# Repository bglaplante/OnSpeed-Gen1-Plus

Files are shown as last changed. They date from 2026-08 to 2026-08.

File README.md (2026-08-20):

# OnSpeed-Gen1-Plus
Takes the original OnSpeed Gen1, ports to Arduino Mega

The original work at https://github.com/flyonspeed-org/OnSpeed-Gen1 used a $50 Due board.
I have ported the project to the Mega, which is sufficient as the Gaussian average was turned off.
This required changing timer libraries and a substantial rework of the code.

Currently as of August 2026, the project has been tested successfully with the Dynon D10A,
which means it works with that and the whole D100 series.

In addition it supports Skyview, and has been bench tested with a data generator emulating
Skyview data.

Garmin G3X is planned.

The project includes an LED display which shows the current reported AOA percent.
This simplifies configuration - you do a test flight at various slow flight speeds and record the reported AOA % values.
Then you can (post-flight) determine the starting thresholds for each OnSpeed point.
Those thresholds can then be placed onto an SD card.  When the system starts, it reads the SD card for configuration values.

A circuit board has been designed to hold the Mega Pro Mini, RS232 converter, LED display, SD card reader, and Step Down power supply.

Licensed under the NC-MIT 1.1 License. See LICENSE file in the project root.

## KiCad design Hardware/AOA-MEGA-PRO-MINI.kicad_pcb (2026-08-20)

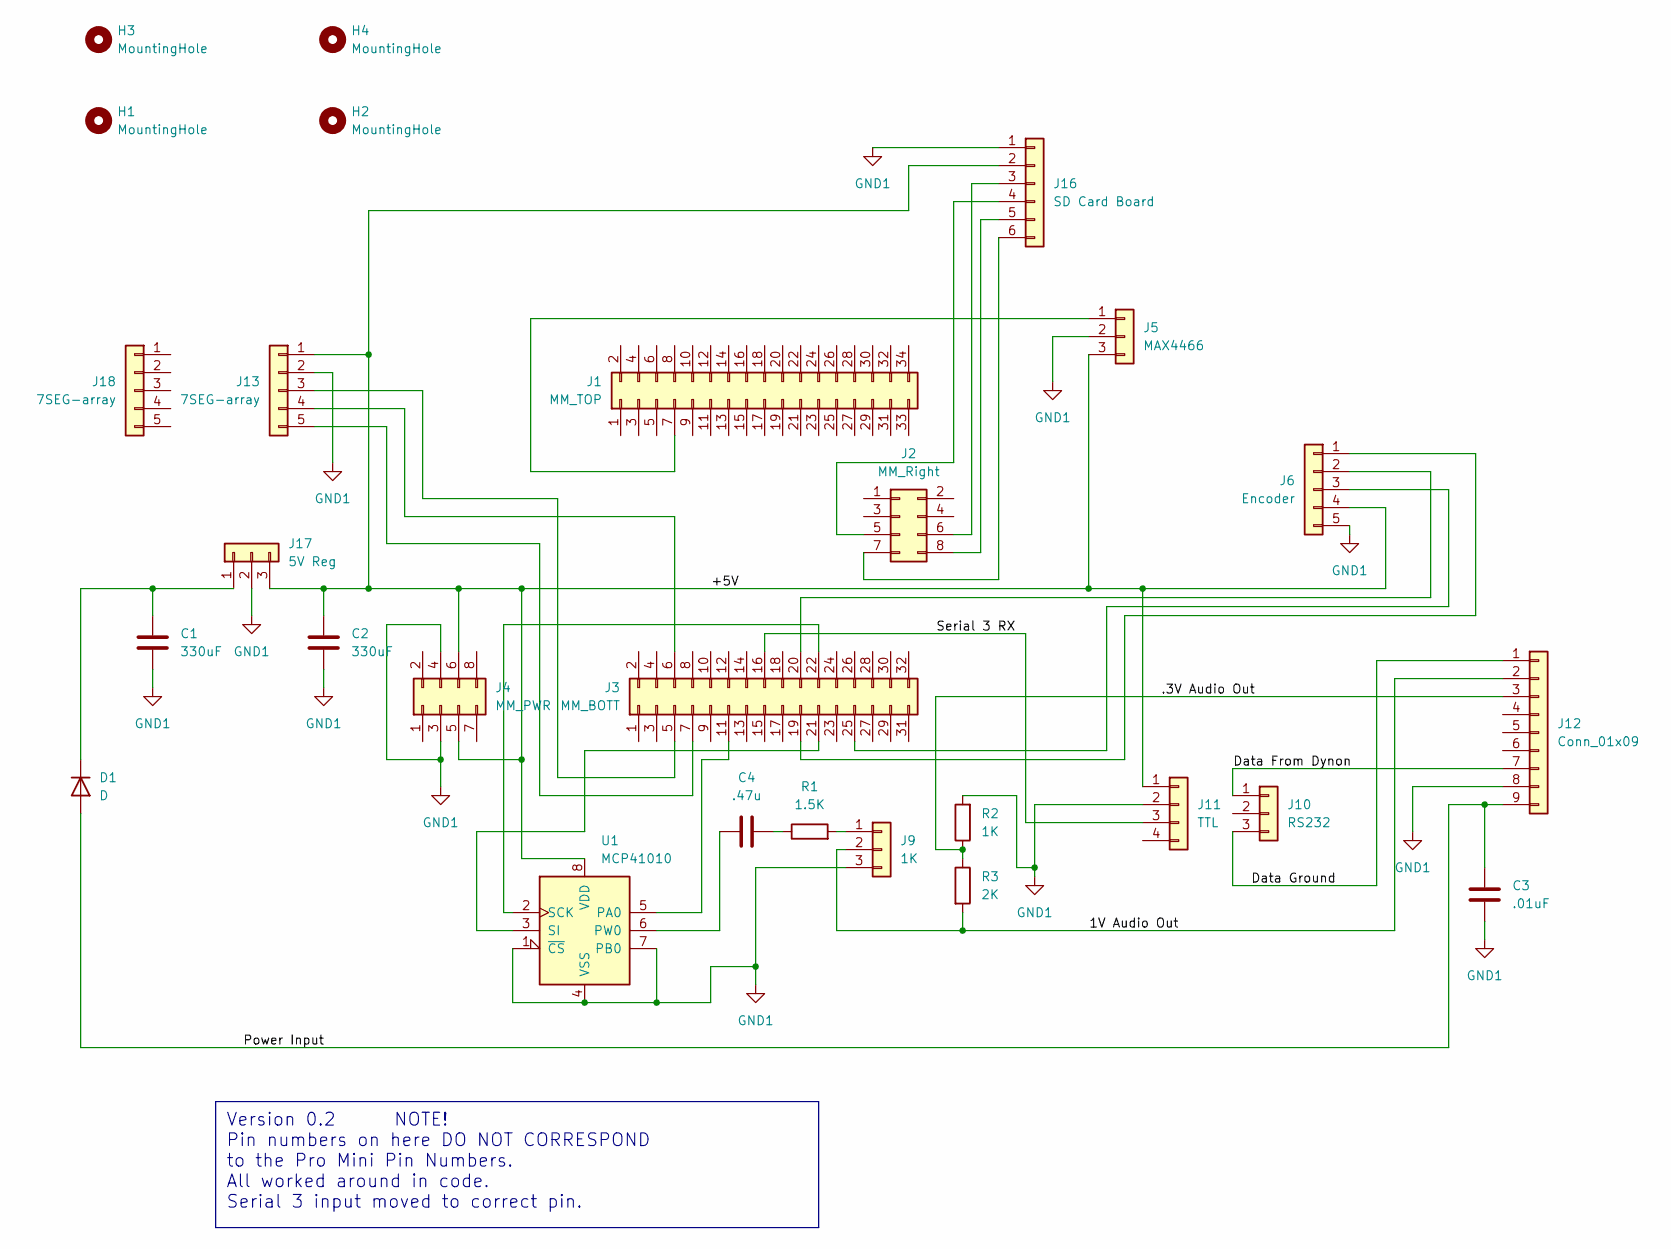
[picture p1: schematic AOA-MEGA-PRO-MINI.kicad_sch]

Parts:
C1, C2: 330uF; CP_Radial_D10.0mm_P5.00mm_P7.50mm
C3: .01uF; CP_Radial_D8.0mm_P5.00mm
C4: .47u; CP_Radial_D7.5mm_P2.50mm
D1: D; D_5W_P10.16mm_Horizontal
H1, H2, H3, H4: MountingHole; MountingHole_3.2mm_M3
J1: MM_TOP; PinSocket_2x17_P2.54mm_Vertical
J2: MM_Right; PinSocket_2x04_P2.54mm_Vertical
J3: MM_BOTT; PinSocket_2x16_P2.54mm_Vertical
J4: MM_PWR; PinSocket_2x04_P2.54mm_Vertical
J5: MAX4466; PinSocket_1x03_P2.54mm_Vertical
J6: Encoder; PinSocket_1x05_P2.54mm_Vertical
J9: 1K; PinSocket_1x03_P2.54mm_Vertical
J10: RS232; PinSocket_1x03_P2.54mm_Vertical
J11: TTL; PinSocket_1x04_P2.54mm_Vertical
J12: Conn_01x09; PinSocket_1x09_P2.54mm_Vertical
J13, J18: 7SEG-array; PinSocket_1x05_P2.54mm_Vertical
J16: SD Card Board; PinSocket_1x06_P2.54mm_Vertical
J17: 5V Reg; PinSocket_1x03_P2.54mm_Vertical
R1: 1.5K; R_1206_3216Metric
R2: 1K; R_1206_3216Metric
R3: 2K; R_1206_3216Metric
U1: MCP41010; DIP-8_W7.62mm

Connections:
/1V Audio Out: J9.2, J12.2, R3.2
/+5V: C2.1, J4.5, J4.6, J5.3, J6.4, J11.1, J13.1, J16.2, J17.3, U1.8 (VDD)
/.3V Audio Out: J12.3, R2.1, R3.1
/Data From Dynon: J10.1, J12.7
/Data Ground: J10.3, J12.1
/Power Input: C3.1, D1.2 (A), J12.9
/Serial 3 RX: J3.16, J11.3
GND1: C1.2, C2.2, C3.2, J4.3, J4.4, J5.2, J6.5, J9.3, J11.2, J12.8, J13.2, J16.1, J17.2, R2.2, U1.1 (~CS), U1.4 (VSS), U1.7 (PB0)
unnamed: C4.2, R1.1
unnamed: C1.1, D1.1 (K), J17.1
unnamed: J1.7, J5.1
unnamed: J3.11, U1.5 (PA0)
unnamed: J3.19, J6.1
unnamed: J3.20, J6.2
unnamed: J3.21, U1.3 (SI)
unnamed: J3.22, U1.2 (SCK)
unnamed: J3.25, J6.3
unnamed: J9.1, R1.2
unnamed: J3.5, J13.3
unnamed: J3.6, J13.4
unnamed: J3.7, J13.5
unnamed: J2.6, J16.3
unnamed: J2.5, J16.4
unnamed: J2.8, J16.5
unnamed: J2.7, J16.6
unnamed: C4.1, U1.6 (PW0)

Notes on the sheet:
Version 0.2 NOTE! Pin numbers on here DO NOT CORRESPOND to the Pro Mini Pin Numbers. All worked around in code. Serial 3 input moved to correct pin.

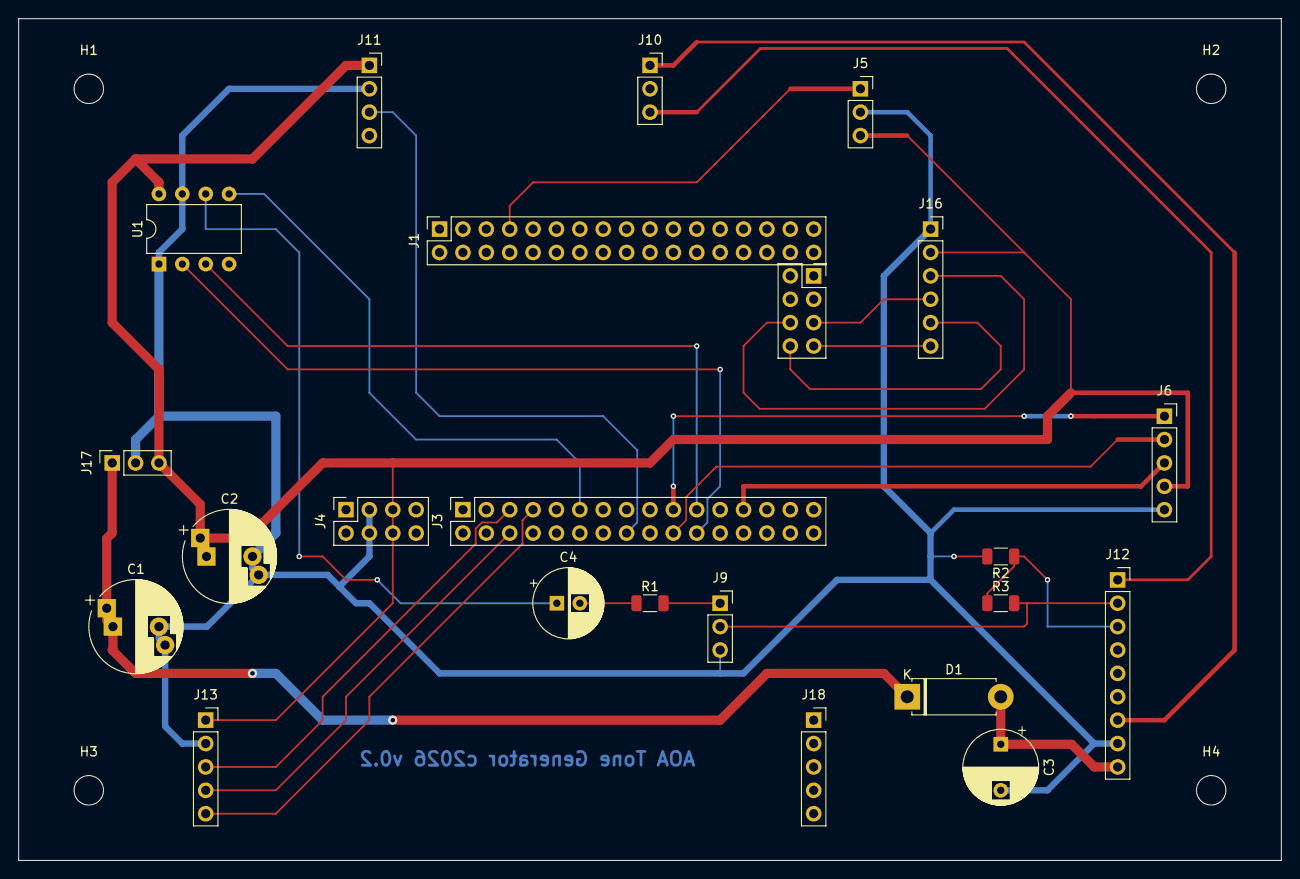
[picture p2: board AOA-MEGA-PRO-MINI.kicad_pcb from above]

Board: 2 copper layers, 137.2 x 91.4 mm, 27 parts (0 on the bottom side), 26 nets.

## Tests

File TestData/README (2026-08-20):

Arduino code to generate Dynon D10A message strings, and to rapidly output them.
By sending strings rapidly and within the range of pulse tone generation speeds we can stress test the system 
to confirm that we do not get data overruns which can lead to lock-up.

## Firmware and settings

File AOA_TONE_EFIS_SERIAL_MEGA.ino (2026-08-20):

////////////////////////////////////////////////////
////////////////////////////////////////////////////
// AOA EFIS Serial to audio tone 
// Supports: Dynon EFIS data using a Arduino Mega board
// Ver 1.7.4
#define VERSION "174"

// NOTE *********  The Arduino default serial buffer is smaller than the Skyview packet,
// it seems that there could easily be an overflow situation.
// however, testing on 8/18, shows can handle Skyview at 100 msgs per second @ SAMPLE_RATE 3
// Bryan LaPlante 8/17/2026 ---  code review Skyview and handle AOA = "XX" it can send 
// Bryan LaPlante 8/12/2026 ---  testing shows no more lockups.  Updated AOA thresholds for N980RV
// Bryan LaPlante 7/1/2026  ---  still get lockups probably buffer overflows... fix volatile vars...
// Bryan LaPlante 6/21/2026 --- pre-calc the pps vs AOA, to eliminate float point (slow) from main loop
// Bryan LaPlante 6/17/2026 --- increase min speed for tones to 15 (at 5 it is alive standing still!)
// Bryan LaPlante 6/14/2026  --- eliminate dual set points ... (Skyview / D100x)
// Bryan LaPlante 11/27/2025 --- read AOA set points from SD card (D10/100 only for now)
// Bryan LaPlante 11/23/2025 --- convert to Mega (for dual hardware serial ports)
// Bryan LaPlante 10/21/2025 --- conversion to Nano, TimerOne, 


//
// - Read data in from Serial3 on MEGA board. (Dynon is at 115200 baud)
// - Serial is used for debugging to computer IDE. (115200 baud)
// - Audio ouput on pin D11  // BGL
// - If no serial data is detected audio tone turns off and LED1 is off
// - MUTE_AUDIO_UNDER_IAS define is used to only activate audio tones if above a given airspeed
//
// - NOTE: Per https://www.iflyez.com/WAITERS_FLIGHT_DATA_RECORDER.pdf, Dynon Dx Series outputs data over 60 times / sec.
// - That can easily lead to Serial buffer overflow.  Default buffer is 64 bytes



// Christopher Jones 6/10/2016
// 6/10/2016  - Started
// 7/09/2018  - 1.5.1 fix for tone PPS between solid tones.  was not calucating the right ratio for the PPS changes.
// 9/02/2018  - 1.5.2 Atempts to fix hang up issues with skyview data.  Changed start up tones.  added more comments. fix min PPS for low tone.
// 9/28/2018  - 1.6.0 Fixed Skyview lockup issue.
// 9/28/2018  - 1.6.1 allow for automatic efis dectection d100 or skyview.

/* ------------  D10A TEST DATA, send via Serial Monitor with CR+NL termination
00082119+058-00541301200+9141+011-01+15003EA0C701A4   -- from Dynon manual
xxxxxxxxxxxxxxxxxxx031xxxxxxxxxxxxxxxxx10xxxxxxxxxx
xxxxxxxxxxxxxxxxxxx031xxxxxxxxxxxxxxxxx15xxxxxxxxxx
xxxxxxxxxxxxxxxxxxx031xxxxxxxxxxxxxxxxx25xxxxxxxxxx
xxxxxxxxxxxxxxxxxxx031xxxxxxxxxxxxxxxxx35xxxxxxxxxx
xxxxxxxxxxxxxxxxxxx031xxxxxxxxxxxxxxxxx55xxxxxxxxxx
xxxxxxxxxxxxxxxxxxx031xxxxxxxxxxxxxxxxx73xxxxxxxxxx
*/

/* ------------ Dynon Skyview TEST DATA, send via Serial Monitor with CR+NL termination
!1121144703-014+00003310811+01736+003-03+1013-033+110831245+01650023176C  -- from Dynon Install Guide
                                           ^^  13 in this case
ADAHRS data starts with !1, others are !2, etc.
Format is 1 based (! is character 1)
AOA is at 44-45 value up to 99, like D100 series
But can be XX for "not available"
!1121144703-014+00003310811+01736+003-03+1010-033+110831245+01650023176C
!1121144703-014+00003310811+01736+003-03+1015-033+110831245+01650023176C
!1121144703-014+00003310811+01736+003-03+1025-033+110831245+01650023176C
!1121144703-014+00003310811+01736+003-03+1035-033+110831245+01650023176C
!1121144703-014+00003310811+01736+003-03+1055-033+110831245+01650023176C
!1121144703-014+00003310811+01736+003-03+1073-033+110831245+01650023176C
*/

#include <TimerOne.h>         // timer lib functions for using DUE timers and callbacks.
#include <Tone.h>
#include <stdint.h>
#include <Arduino.h>
#include <SPI.h>
#include <SdFat.h>            // so we can provide easily modifiable config file
#include <LedControl.h>       // so can display airspeed and Dynon AOA %

// #include <Gaussian.h>         // gaussian lib used for avg out AOA values.
// #include <LinkedList.h>       // linked list is also required.
// #include <GaussianAverage.h>  // more info at https://github.com/ivanseidel/Gaussian

// Output serial debug infomation. (comment out the following line to turn off serial debug output)
#define SHOW_SERIAL_DEBUG 
// #define SHOW_SERIAL_DEBUG_PLUS

// Average out AOA values to give a smoother transtition between values.
//#define USE_AOA_AVERAGE
// set how many previous AOA values we store to create avg and help smooth out the data values.
#define AOA_HISTORY_MAX       5

// set Freq of callback function used to create the pulse tones.
#define FREQ_OF_FUNCTION      100       // times per second

// set the sample rate of how often to pull the AOA value from the serial stream.
// example 
// 1 = sample every AOA value received from the efis.
// 5 = skip every 5 lines then sample the AOA value.
#define SERIAL_SAMPLE_RATE    3  // note, this means test data needs to be sent N times too

// Min airspeed in knots before the audio tone is turned on
// This is useful because if your on the ground you don't need a beeping in your ear.
#define MUTE_AUDIO_UNDER_IAS  15

// Expected serial string lengths
#define DYNON_SERIAL_LEN              53  // with CR LF counted
#define DYNON_SKYVIEW_SERIAL_LEN      74
#define GARMIN_G3X_SERIAL_LEN         59  

// array postions for aoa values
#define POS_HIGH_TONE_AOA_STALL   0      // % (and above) where stall happens.
#define POS_HIGH_TONE_AOA_START   1      // % (and above) where high tone starts
#define POS_LOW_TONE_AOA_SOLID    2      // % (and above) where a solid low tone is played.
#define POS_LOW_TONE_AOA_START    3      // % (and above) where low 
#define ALL      0                       // array index, now all units share one slot

int AoaToneMatrix[1][5];          // tone matrix for different efis units.
// unsigned char WhichEFIS = D100;   // detect which efis is being read and set store it here.

// general tone settings. Tone Pulse Per Sec (PPS)  (used for all efis units)
#define HIGH_TONE_STALL_PPS       20      // how many PPS to play during stall
#define HIGH_TONE_PPS_MAX         6.5     // 6.5   
#define HIGH_TONE_PPS_MIN         1.5     // 1.5
#define HIGH_TONE_HZ              1600    // freq of high tone
//#define HIGH_TONE2_HZ             1500    // a 2nd high tone that it will cycle between (if defined)
#define LOW_TONE_PPS_MAX          8.5
#define LOW_TONE_PPS_MIN          1.5
#define LOW_TONE_HZ               400     // freq of low tone

#define BAUDRATE_EFIS         115200  // baud rate for D100/D10 and dynon and G3x

#define TONE_PIN              10    // audio output
#define PIN_LED1              13    // internal LED for showing AOA status.
#define PIN_LED2              54    // aka A0. external LED for showing serial input.
#define DEBUG_PIN             41    // if jumpered low, we read input from the USB port
#define SEVENSEG_DATA_PIN      4    // 7 segment display
#define SEVENSEG_CLK_PIN       6    //  "
#define SEVENSEG_CS_PIN        5    //  "

#define PULSE_TONE            1
#define SOLID_TONE            2
#define TONE_OFF              3
#define STARTUP_TONES_DELAY   120
#define STARTUP_TONES_DELAY2  300


volatile uint8_t toneState = false;
volatile uint8_t toneMode = TONE_OFF;    // current mode of tone.  PULSE_TONE, SOLID_TONE, or TONE_OFF
volatile boolean highTone = false;       // are we playing high tone or low tone?
volatile uint16_t toneFreq = 0;       // store current freq of tone playing.
volatile uint8_t AOA = 0;             // avaraged AOA value is stored here.

uint8_t sampleCount = 0;              // used for pulling 1/N sample message from input
float pps = 0;                        // store current PPS of tone (used for debuging) 
uint8_t liveAOA;                      // realtime AOA value.
uint8_t lastAOA = 111;                // save last AOA value here. impossible value so start up works 
unsigned int ALT = 0;                 // hold ALT (only used for debuging)
int ASI = 0;                          // live Air Speed Indicated
unsigned long cyclesWOSerialData = 0; // keep track if not serial data is recieved.
//unsigned char efisTypeDetected = 0; // auto detect which efis is being used. 0 no detection. 1 = D series, 2 = Skyview
//GaussianAverage myAverageAOA = GaussianAverage(AOA_HISTORY_MAX);

float ppsLookup[100];                 // pre-calculate pps values for all 100 possible AOA --- performance

boolean usbMode;                      // Rcv data via USB for bench testing

// SD_CS_PIN should be defined according to your hardware setup
const uint8_t SD_CS_PIN = 53; 
SdFat sd;                             // SD card stuff...
File myFile;

// vars for converting AOA scale value to PPS scale value.
int OldRange,  OldValue;
float NewRange, NewValue;

char inChar;                    // store single serial input char here.
#define MAXSIZE 90              // max length of string
char input[MAXSIZE+1];          // buffer for full serial data input string.
uint8_t inputPos = 0;           // current postion of serial data.
char tempBuf[90];               // misc char buffer used for debug


Tone tonePlayer[1];    // create
LedControl myDisp = LedControl(SEVENSEG_DATA_PIN, SEVENSEG_CLK_PIN, SEVENSEG_CS_PIN, 1);  // Data, Clk, CS, #Devices

bool sdStart(){
  Serial.print("Initializing SD card...");  
  if (!sd.begin(SD_CS_PIN)) {
    Serial.println("initialization failed!");
    sdFailed();
    return false;
  }
  Serial.println("initialization done.");
  
  myFile = sd.open("aoaconfig.txt", FILE_READ);
  if (!myFile) {
    Serial.println("File Open of aoaconfig.txt failed");
    sdFailed();
    return false;
  }

  if (myFile) {
    Serial.println("aoaconfig.txt:");

    readConfig();  // pick up configuration values from SD
    
    // close the file:
    myFile.close();
  } else {
    // if the file didn't open, print an error:
    Serial.println("error opening aoaconfig.txt");
    sdFailed();
    return false;
  }  
  return true;
}

float preCalcPPS(int AOA) {               // overrides global AOA
  // used by setup to pre-load AOA array
  
  // check AOA value and set tone and pauses between tones according to 
  if(AOA >= AoaToneMatrix[ALL][POS_HIGH_TONE_AOA_STALL]) {
    return (HIGH_TONE_STALL_PPS);
    
    // in this code "Old" refers to the inputs before rescaling, that is AOA values
    // "New" refers to output of the math, which are PPS values
    
  } else if(AOA >= AoaToneMatrix[ALL][POS_HIGH_TONE_AOA_START]) {
    // play HIGH tone at Pulse Rate 1.5 PPS to 6.2 PPS (depending on AOA value)

    OldValue = AOA-(AoaToneMatrix[ALL][POS_HIGH_TONE_AOA_START]-1);
    // scale number using this. http://stackoverflow.com/questions/929103/convert-a-number-range-to-another-range-maintaining-ratio
    OldRange = AoaToneMatrix[ALL][POS_HIGH_TONE_AOA_STALL] - AoaToneMatrix[ALL][POS_HIGH_TONE_AOA_START]; //20 - 1;  //(OldMax - OldMin)  
    NewRange = HIGH_TONE_PPS_MAX - HIGH_TONE_PPS_MIN; // (NewMax - NewMin)  
    NewValue = (((OldValue - 1) * NewRange) / OldRange) + HIGH_TONE_PPS_MIN; //(((OldValue - OldMin) * NewRange) / OldRange) + NewMin
    return (NewValue);
  } else if(AOA >= AoaToneMatrix[ALL][POS_LOW_TONE_AOA_SOLID]) {
    // play a steady LOW tone
    return 0.0;
  } else if(AOA >= AoaToneMatrix[ALL][POS_LOW_TONE_AOA_START]) {
    // play LOW tone at Pulse Rate 1.5 PPS to 8.2 PPS (depending on AOA value)
    // scale number using this. http://stackoverflow.com/questions/929103/convert-a-number-range-to-another-range-maintaining-ratio
    OldValue = AOA - AoaToneMatrix[ALL][POS_LOW_TONE_AOA_START];
    OldRange = AoaToneMatrix[ALL][POS_LOW_TONE_AOA_SOLID] - AoaToneMatrix[ALL][POS_LOW_TONE_AOA_START]; //40 - 1;  //(OldMax - OldMin)  
    NewRange = LOW_TONE_PPS_MAX - LOW_TONE_PPS_MIN; // (NewMax - NewMin)  
    NewValue = (((OldValue - 1) * NewRange) / OldRange) + LOW_TONE_PPS_MIN; //(((OldValue - OldMin) * NewRange) / OldRange) + NewMin
    return (NewValue);
  } else {  
    // low AOA, below any tones
    return 0.0;
  }  
}
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
void loop() {
      // check for serial in from efis.      

// sampleCount, if not zero, pull and discard data.  on \n decrement sampleCount         
      while(inputAvailable() && (sampleCount > 0)) {
        inChar = readChar();
        if (inChar == '\n') { 
          /*
          Serial.print("skipped line @ sampleCount ");          
          Serial.println(sampleCount);
          */
          sampleCount -= 1;        // EOL, decrement
          inputPos = 0; 
        }  
      }      

      // data we want to look at
      while(inputAvailable() && (sampleCount == 0)) {     // from whichever port
        inChar = readChar();       

        if (inputPos >= MAXSIZE) {     // first thing, check for overrun
          inputPos = 0;                // reset pointer
          Serial.println("OVER FLOW DATA");
          input[MAXSIZE] = '\0';       // null terminate it
          Serial.println(input);
        }

        input[inputPos]=inChar;         // save into string buffer.
        inputPos++;                     // increment the string buffer postion.
        cyclesWOSerialData = 0;         // reset the var thats keep track of when we last had serial data
                                        // (used for turning off tone if no serial data found)
        if (inputPos == 1) {
          myDisp.setChar(0,7,'d',false);  // indicate Rx of data
        }

        // check for dynon skyview data. based on length of string and if the 1st 2 chars match
        if (inChar == '\n' && inputPos == DYNON_SKYVIEW_SERIAL_LEN && input[0]=='!' && input[1]=='1') {
          // WhichEFIS = SKYVIEW;  // set skyview efis detected.
          // skyview data starts with a '!1'... the D series efis has no line prefix.  
          tempBuf[0] = input[43]; // get the 2 bytes for aoa on skyview.
          tempBuf[1] = input[44]; // 
          tempBuf[2] = '\0'; // term string  (needed for when we convert a string to a int in the next line)
          // Skyview may put "XX" into AOA when it is not available
          if (input[42] != 'X') { 
            liveAOA = strtol(tempBuf, NULL, 10);  //convert to int

            // get AOA value (check if we are using a Gaussian function to smooth the values)
#ifdef USE_AOA_AVERAGE
            myAverageAOA += liveAOA;            // store and calcute the mean average AOA from previous values.
            AOA = myAverageAOA.process().mean;
#else          
            AOA = liveAOA;  // else just use the live AOA value.
#endif
          }  // end handling of "XX" AOA
          // get ASI (4 digits) but we only want the first 3. we don't need a 10/th of a knot
          tempBuf[0] = input[23]; //
          tempBuf[1] = input[24]; //
          tempBuf[2] = input[25]; //
          tempBuf[3] = '\0'; //
          ASI = strtol(tempBuf, NULL, 10); //convert to int (data comes in knots already on skyview)

#ifdef SHOW_SERIAL_DEBUG_PLUS    
  // show serial debug info for skyview data found.
  // can't edit the tempBuf here.. was causing crash. Christopher. 9/26/2018
  //sprintf(tempBuf, "SKYVIEW AOA:%i Live:%i ASI:%ikts ALT:%i PPS:%f cycleCounterResetAt: %i",AOA, liveAOA, ASI, ALT, pps, cycleCounterResetAt);
  //Serial.println(tempBuf);
          Serial.print("SKYVIEW AOA ");
          if (input[42] != 'X') { Serial.println(AOA);
          } else { Serial.println("XX");}
#endif
          if (input[42] != 'X') {
            validAOADataFound();  // run function to process tone.  because we found a valid AOA value.
          }

// -------------------  END OF SKYVIEW LOGIC ----------------------------------------
// -------------------  START D10A LOGIC --------------------------------------------
          
        } else if (inChar == '\n' && inputPos == 53) {  // is EOL? 
          // WhichEFIS = D100;  // set D100 or D10A efis detected
          // get AOA from dynon efis string.  details of format can be found from dynon pdf manual.
          tempBuf[0] = input[39]; //
          tempBuf[1] = input[40]; //
          tempBuf[2] = '\0'; //term string (needed for converting a string to a int in the next line)
          liveAOA = strtol(tempBuf, NULL, 10); //convert to int

          // get AOA value (check if we are using a Gaussian function to smooth the values)
#ifdef USE_AOA_AVERAGE
          myAverageAOA += liveAOA;            // store and calcute the mean average AOA from previous values.
          AOA = myAverageAOA.process().mean;
#else          
          AOA = liveAOA;  // else just use the live AOA value.
#endif
      
          // get ASI (4 digits) but we only want the first 3 because its in meters per second.
          tempBuf[0] = input[20]; //
          tempBuf[1] = input[21]; //
          tempBuf[2] = input[22]; //
          tempBuf[3] = '\0'; // terminate string (needed for converting a string to a int in the next line)
          ASI = strtol(tempBuf, NULL, 10) * 1.943; //convert to int (and from m/s to knots)

          // get ALT (4 digits) in meters.. this is really not used for this application.  we just collect it to show in debug.
          tempBuf[0] = input[25]; //
          tempBuf[1] = input[26]; //
          tempBuf[2] = input[27]; //
          tempBuf[3] = input[28]; //
          tempBuf[4] = '\0'; //
          // ALT = (strtol(tempBuf, NULL, 10) * 0.328) * 10; //convert to long (and from meters to feet)
          validAOADataFound();    // run function to process tone.  because we found a valid AOA value.

#ifdef SHOW_SERIAL_DEBUG    
          // Serial.print("D100 AOA ");
          // Serial.println(AOA);
#endif
        // ----------------- END OF D10A/D100 LOGIC ----------------------------
        // ----------------- START G3X LOGIC -----------------------------------
        } else if(inChar == '\n' && inputPos == 59) { 
          // WhichEFIS = G3X;  // set efis detected
          // efisTypeDetected != SKYVIEW has been added to make sure we don't confuse skyview data for d10 data and try to process..
          // get AOA from dynon efis string.  details of format can be found from dynon pdf manual.
          tempBuf[0] = input[43]; //
          tempBuf[1] = input[44]; //
          tempBuf[2] = '\0'; //term string (needed for converting a string to a int in the next line)
          liveAOA = strtol(tempBuf, NULL, 10); //convert to int

          // get AOA value (check if we are using a Gaussian function to smooth the values)
#ifdef USE_AOA_AVERAGE
          myAverageAOA += liveAOA;            // store and calcute the mean average AOA from previous values.
          AOA = myAverageAOA.process().mean;
#else          
          AOA = liveAOA;  // else just use the live AOA value.
#endif
      
          // get ASI (4 digits) but we only want the first 3 because 1/10th of a Knot.
          tempBuf[0] = input[23]; //
          tempBuf[1] = input[24]; //
          tempBuf[2] = input[25]; //
          tempBuf[3] = '\0'; // terminate string (needed for converting a string to a int in the next line)
          ASI = strtol(tempBuf, NULL, 10);  //convert to int 

          validAOADataFound();

#ifdef SHOW_SERIAL_DEBUG    
          Serial.print("G3X AOA ");
          Serial.println(AOA);
#endif       
        } 

        if (inChar == '\n') {
          // if we are at the end of line then reset postion to start looking for a new line.
          inputPos = 0; 
          sampleCount = SERIAL_SAMPLE_RATE -1;    // reset
        } 
        
      }  // end while inputAvailable (and is a line we wish to sample)

      // check if no serial has been sent in a while.
      cyclesWOSerialData++;
      // delay(200);                           // *************  MY BENCH DEBUG *************
      if(cyclesWOSerialData > 666000) {
        //TODO:  should we do something more to inidicate to the user there is no serial data coming in?  
        // this might be useful for troubleshooting after a install.
        // perhaps a warning light?
        toneMode = TONE_OFF;        // stop tone
        lastAOA = 0;                // reset AOA
        cyclesWOSerialData == 0;
        digitalWrite(PIN_LED2, 0);  // no EFIS serial data so turn off led.
        myDisp.setChar(0,0,'-',false);  // indicate no data
        myDisp.setChar(0,1,'-',false);
        myDisp.setChar(0,7,' ',false);  // clear the 'd' character
#ifdef SHOW_SERIAL_DEBUG    
       // Serial.println("NO DATA");  // *********** TEMP turn off to avoid overwhelming monitor *********
#endif
      } 
}
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

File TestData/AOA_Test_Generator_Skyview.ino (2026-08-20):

// THIS VERSION IS TO SEND DYNON D10A / D100 SERIES DATA STRINGS

// Bryan LaPlante
// Since we are running the AOA tone generator on a Mega, without floating point hardware
// we need to insure that the input buffer does not get overrun.
// When processing every sample, on the Dx Dynon, it appears that overrun did happen on
// the pre 6/17/2026 version.
//
// Dynon can send 60 strings per second.  So we need to confirm that
// even at faster rates there are no overflows, hangs, crashes.
// This is even more critical for the Skyview format which is longer than the Serial
// hardware buffer size
//
// Most critical in the current code is the floating point math that happens when the tone
// is in a range that requires calculation of pps (pulses per second), and that the AOA
// value changed from last time.
//
// At 115,200 Baud, The Dx sentance takes 4.6ms, and would arrive every 16.6ms

#define BAUDRATE_EFIS 115200
#define DELAY_MS   5        // 100mS = 10/sec, 10mS, approx 100/sec
// #define DELAY_MS   100
#define AOA_MIN    10
#define AOA_MAX    50
#define AOA_REPEAT  2       // how many times to send same value

/* ------------ Dynon Skyview TEST DATA, send via Serial Monitor with CR+NL termination
!1121144703-014+00003310811+01736+003-03+1013-033+110831245+01650023176C  -- from Dynon Install Guide
                                           ^^  13 in this case
ADAHRS data starts with !1, others are !2, etc.
Format is 1 based (! is character 1)
AOA is at 44-45 value up to 99, like D100 series
But can be XX for "not available"
!1121144703-014+00003310811+01736+003-03+1010-033+110831245+01650023176C
*/

String sOne = "!1121144703-014+00003310811+01736+003-03+10";  // before two digit AOA
String sTwo = "-033+110831245+01650023176C";                               // after it
 

void setup() {
  // put your setup code here, to run once:
  Serial.begin(BAUDRATE_EFIS);
}

void loop() {
  // put your main code here, to run repeatedly:
  uint8_t i = AOA_MIN;
  while (true){
    for (int y = 0; y < AOA_REPEAT; y++) {
      Serial.print(sOne);       // first part
      Serial.print(i, DEC);     // the AOA
      Serial.println(sTwo);     // rest of the line
      delay(DELAY_MS);
    }
    i++;
    if (i > AOA_MAX) {i = AOA_MIN;}
  }
}

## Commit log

2026-08-20 More details.
    Added details about the LED display and configuration process.
2026-08-20 Arduino Mega Code
2026-08-20 Update README
    Added description of Arduino code functionality and stress testing.
2026-08-20 KiCad files
    [AOA-MEGA-PRO-MINI.kicad_pcb, AOA-MEGA-PRO-MINI.kicad_sch]
2026-08-20 Update README with circuit board version information
